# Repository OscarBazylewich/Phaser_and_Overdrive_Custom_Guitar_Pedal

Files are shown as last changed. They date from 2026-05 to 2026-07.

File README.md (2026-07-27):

# Phaser_and_Overdrive_Custom_Guitar_Pedal
This projects attemps to recreate and try to improve upon popular guitar pedals such as the MXR Phase 90 and the BOSS-OD1 by incorporating modern analog circuit design and PCB design. This repository will include an LTSpice schematic as well as 3rd party components utilized in the schematic. The same thing also applies for KiCAD.

Final Project PCB layout:  


How to import 3rd Party Models in LTSpice:
1. Download .sub and .asy files in the LTSpice found in the LTSpice folder.
2. Place the associated files to your local LTSpice directory where the .sub files go into the sub folder and the .asy files fo into the sym folder.

note: 3rd party models might get deleted once ltspice gets updated so its recommended to have a separate folder containing all your 3rd party models then manually copying each file into the directory.

How to import 3rd party symbols, footprints, and models into KiCAD:
1. Place and extract zip files into a directory of your choosing.
2. To import symbols, go into the symbol editor and click on the preferences tab and head onto manage symbol libraries. Then, click the folder icon and look for the directiory where you placed your zip files and import files ending in .kicad_sym.
3. For footprints, go into the footprint editor and click on the preferences tab and head onto manage footprint libraries. Then, click the folder icon and look for the directiory where you placed your zip files and import files ending in .kicad_mod.

Preview of Circuit in LTSpice



Sample Simulations of the circuit





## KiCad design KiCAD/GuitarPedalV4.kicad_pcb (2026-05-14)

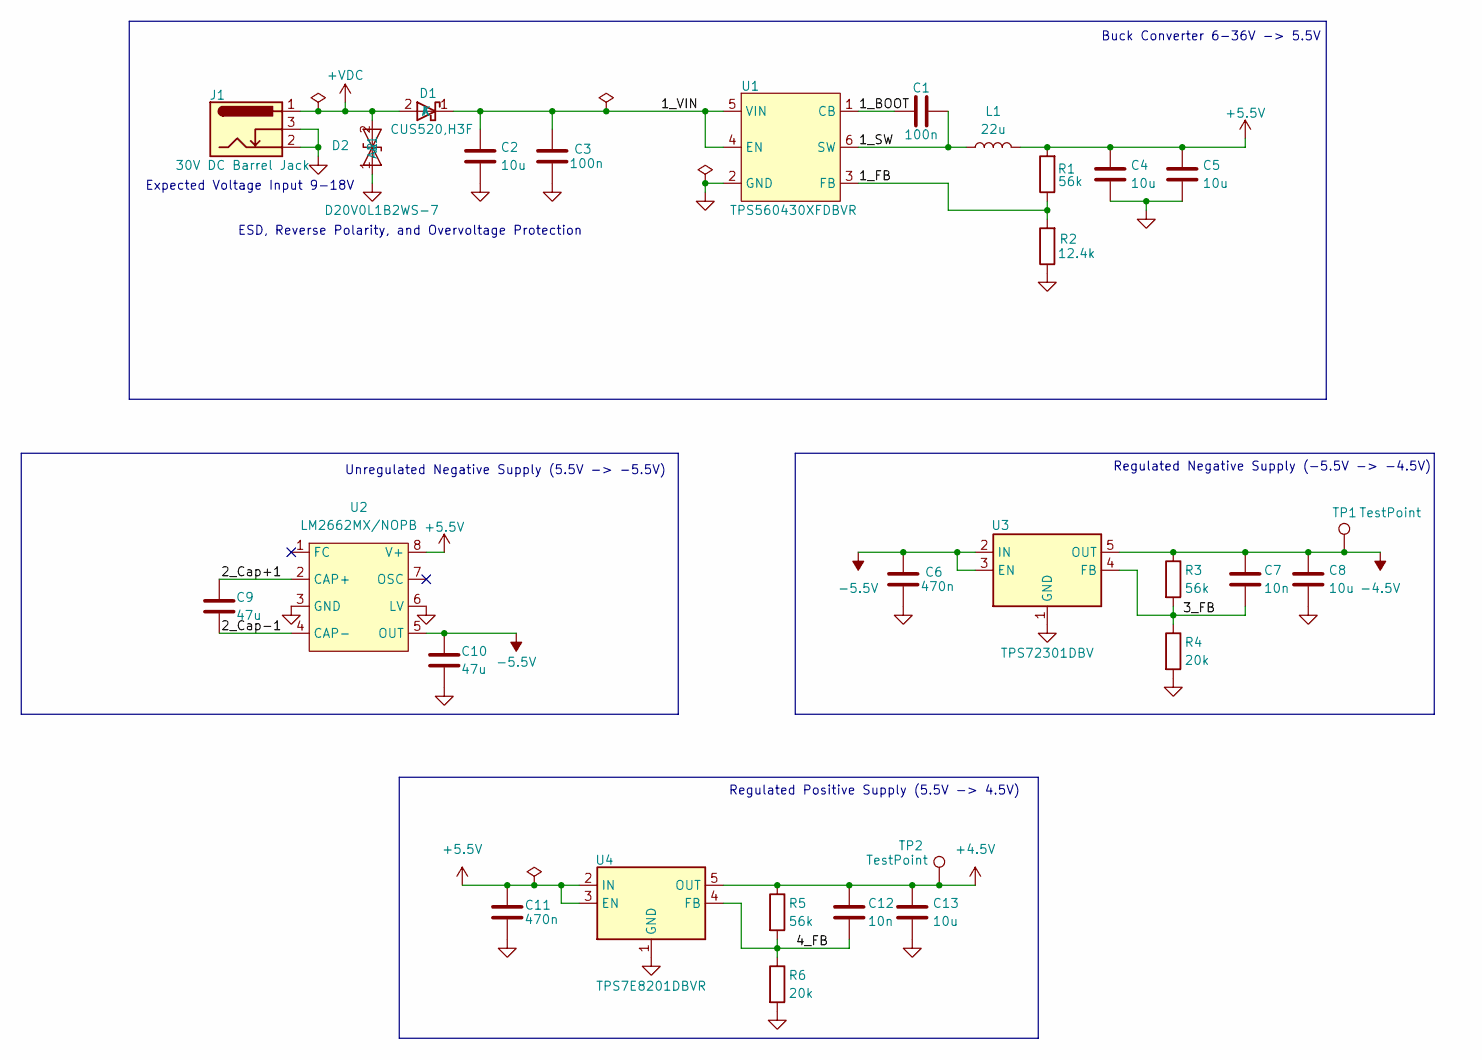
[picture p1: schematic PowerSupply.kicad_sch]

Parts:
C1, C3: 100n; C_0603_1608Metric_Pad1.08x0.95mm_HandSolder; Manufacturer Part Number C1608X5R1H104K080AA
C2, C4, C5, C8, C13: 10u; C_0805_2012Metric_Pad1.18x1.45mm_HandSolder; Manufacturer Part Number C2012X5R1H106K125AC
C6, C11: 470n; C_0603_1608Metric_Pad1.08x0.95mm_HandSolder; Manufacturer Part Number CGA3E1X7R1V474K080AC
C7, C12: 10n; C_0603_1608Metric_Pad1.08x0.95mm_HandSolder; Manufacturer Part Number CGA3E2X7R1H103K080AA
C9, C10: 47u; C_1206_3216Metric_Pad1.33x1.80mm_HandSolder; Manufacturer Part Number C3216X5R1E476M160AC
D1: CUS520,H3F; D_SOD-323_HandSoldering; Manufacturer Part Number CUS520,H3F
D2: D20V0L1B2WS-7; D_SOD-323_HandSoldering; Manufacturer Part Number D20V0L1B2WS-7
J1: 30V DC Barrel Jack; BarrelJack_GCT_DCJ200-10-A_Horizontal; Manufacturer Part Number 694106301002
L1: 22u; L_0805_2012Metric_Pad1.05x1.20mm_HandSolder; Manufacturer Part Number MLZ2012P220WTD25
R1, R3, R5: 56k; R_0603_1608Metric_Pad0.98x0.95mm_HandSolder; Manufacturer Part Number CRCW060356K0FKEA
R2: 12.4k; R_0603_1608Metric_Pad0.98x0.95mm_HandSolder; Manufacturer Part Number CRCW060312K4FKEA
R4, R6: 20k; R_0603_1608Metric_Pad0.98x0.95mm_HandSolder; Manufacturer Part Number CRCW060320K0FKEC
TP1, TP2: TestPoint; TestPoint_Pad_1.0x1.0mm
U1: TPS560430XFDBVR; SOT-23-6; Manufacturer Part Number TPS560430XFDBVR
U2: LM2662MX/NOPB; SOIC-8_3.9x4.9mm_P1.27mm; Manufacturer Part Number LM2662MX/NOPB
U3: TPS72301DBV; SOT-23-5_HandSoldering; Manufacturer Part Number TPS72301DBVRG4
U4: TPS7E8201DBVR; SOT-23-5_HandSoldering; Manufacturer Part Number TPS7E8201DBVR

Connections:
+4.5V: C12.1, C13.1, R5.1, TP2.1 (1_1), U4.5 (OUT); also elsewhere on the board
+5.5V: C4.1, C5.1, C11.2, L1.2, R1.2, U2.8 (V+), U4.2 (IN), U4.3 (EN)
+VDC: D1.2 (A), D2.2 (A2), J1.1
-4.5V: C7.1, C8.1, R3.1, TP1.1 (1_1), U3.5 (OUT); also elsewhere on the board
-5.5V: C6.2, C10.1, U2.5 (OUT), U3.2 (IN), U3.3 (EN)
/Power Supply Section/1_BOOT: C1.2, U1.1 (CB)
/Power Supply Section/1_FB: R1.1, R2.2, U1.3 (FB)
/Power Supply Section/1_SW: C1.1, L1.1, U1.6 (SW)
/Power Supply Section/1_VIN: C2.1, C3.2, D1.1 (K), U1.4 (EN), U1.5 (VIN)
/Power Supply Section/2_Cap+1: C9.1, U2.2 (CAP+)
/Power Supply Section/2_Cap-1: C9.2, U2.4 (CAP-)
/Power Supply Section/3_FB: C7.2, R3.2, R4.1, U3.4 (FB)
/Power Supply Section/4_FB: C12.2, R5.2, R6.1, U4.4 (FB)
GND: C2.2, C3.1, C4.2, C5.2, C6.1, C8.2, C10.2, C11.1, C13.2, D2.1 (A1), J1.2, J1.3, R2.1, R4.2, R6.2, U1.2 (GND), U2.3 (GND), U2.6 (LV), U3.1 (GND), U4.1 (GND); also elsewhere on the board

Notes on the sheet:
Regulated Negative Supply (-5.5V -> -4.5V)
ESD, Reverse Polarity, and Overvoltage Protection
Regulated Positive Supply (5.5V -> 4.5V)
Unregulated Negative Supply (5.5V -> -5.5V)
Expected Voltage Input 9-18V
Buck Converter 6-36V -> 5.5V

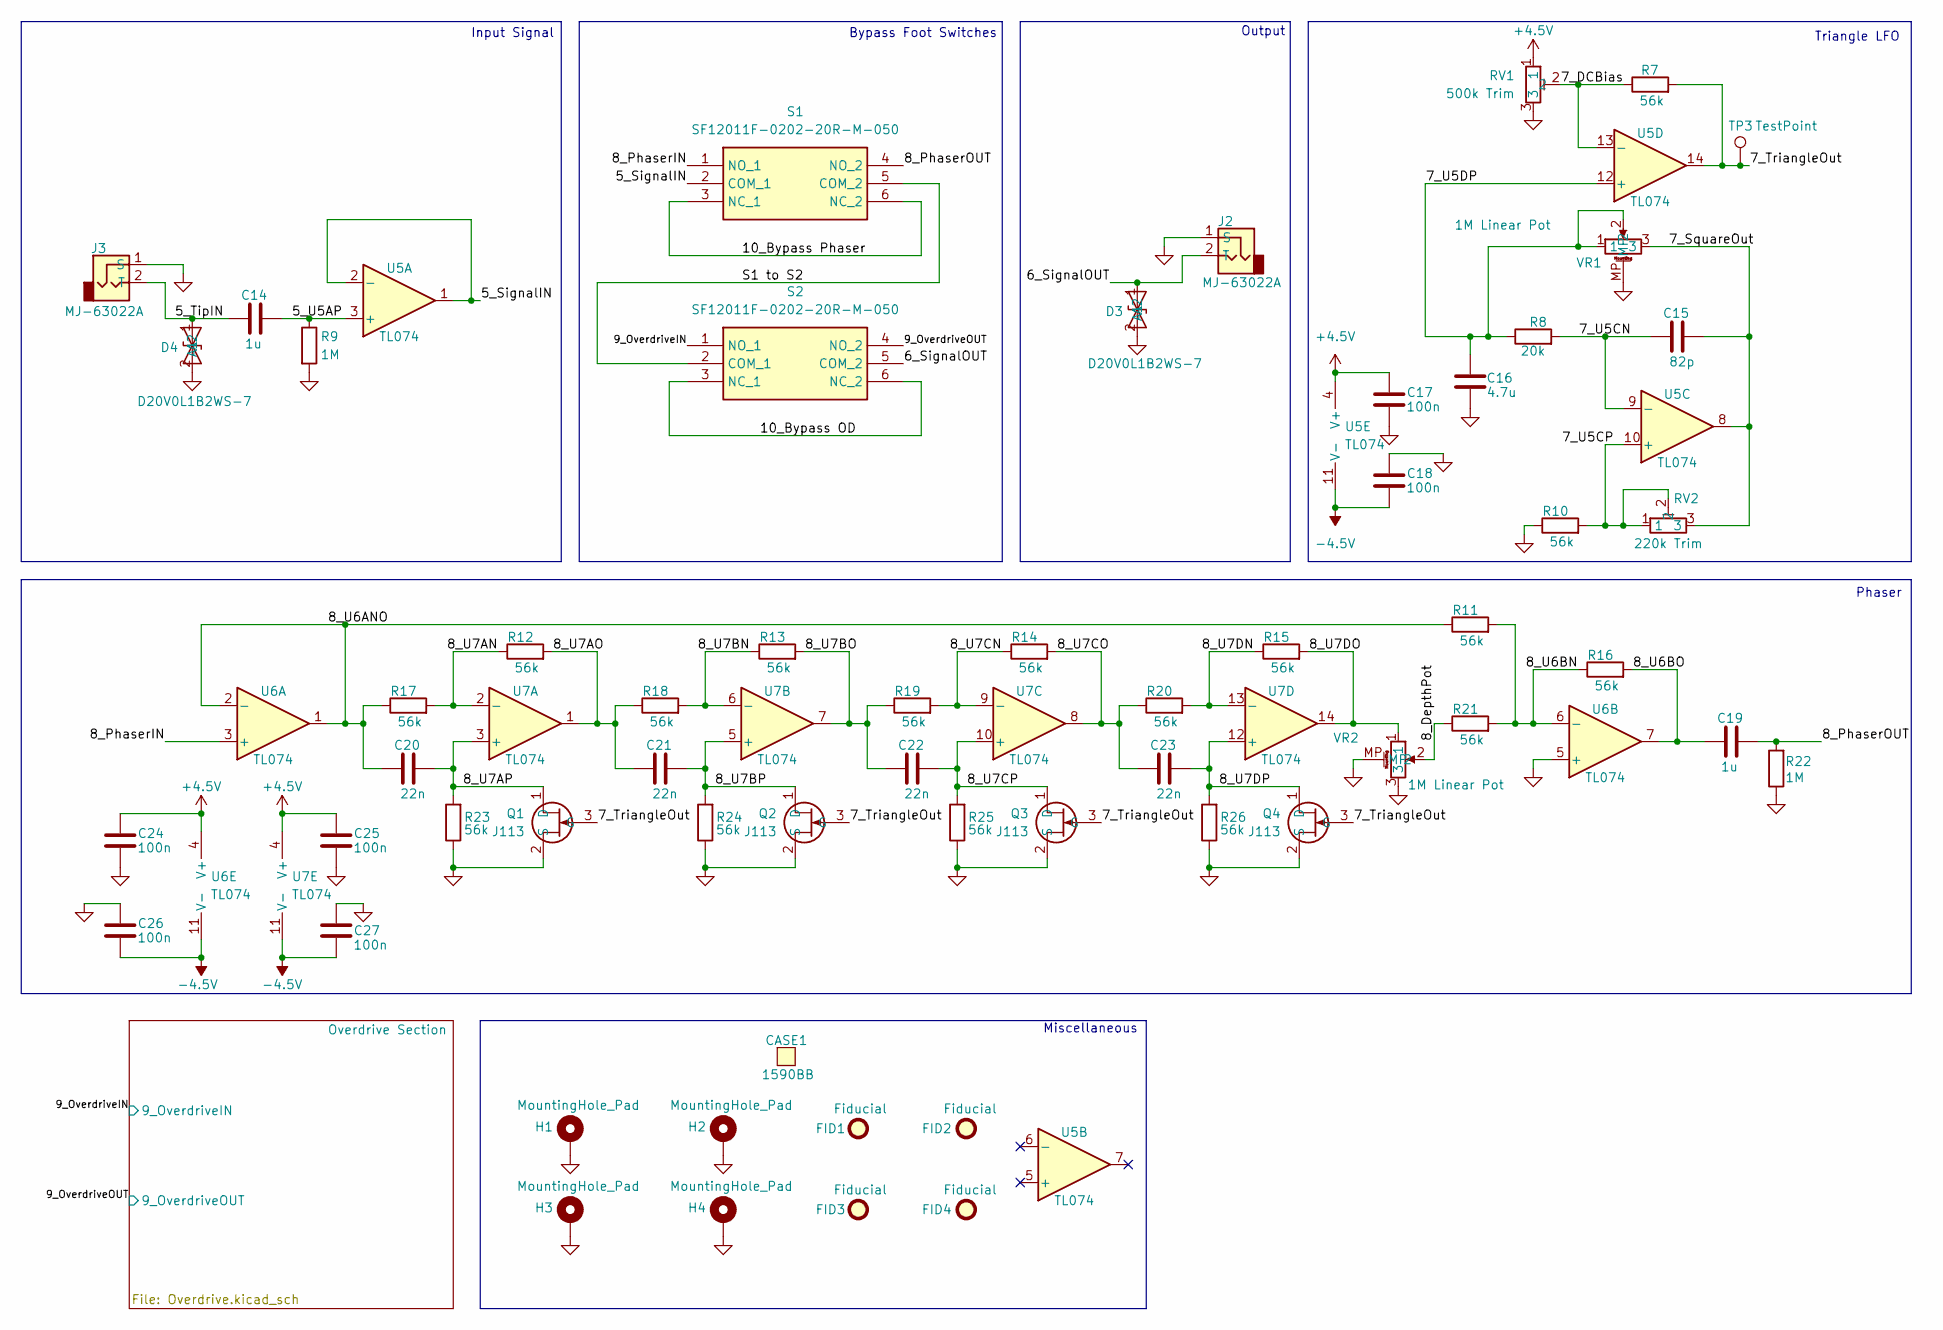
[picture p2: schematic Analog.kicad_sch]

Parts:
C14, C19: 1u; C_Rect_L7.2mm_W4.5mm_P5.00mm_FKS2_FKP2_MKS2_MKP2; Manufacturer Part Number B32529C0105J189
C15: 82p; C_Disc_D3.8mm_W2.6mm_P2.50mm; Manufacturer Part Number K820J15C0GF5TL2
C16: 4.7u; C_Rect_L18.0mm_W7.0mm_P15.00mm_FKS3_FKP3; Manufacturer Part Number B32522C0475J000
C17, C18, C24, C25, C26, C27: 100n; C_0603_1608Metric_Pad1.08x0.95mm_HandSolder; Manufacturer Part Number C1608X5R1H104K080AA
C20, C21, C22, C23: 22n; C_Rect_L7.2mm_W2.5mm_P5.00mm_FKS2_FKP2_MKS2_MKP2; Manufacturer Part Number B32529C1223J289
CASE1: 1590BB; Manufacturer Part Number 1590BB
D3, D4: D20V0L1B2WS-7; D_SOD-323_HandSoldering; Manufacturer Part Number D20V0L1B2WS-7
FID1, FID2, FID3, FID4: Fiducial
H1, H2, H3, H4: MountingHole_Pad; MountingHole_3.2mm_M3_Pad
J2, J3: MJ-63022A; MJ63022A; Manufacturer Part Number MJ-63022A
Q1, Q2, Q3, Q4: J113; 2N3904BU; Manufacturer Part Number J113
R7, R10, R11, R12, R13, R14, R15, R16, R17, R18, R19, R20, R21, R23, R24, R25, R26: 56k; R_0603_1608Metric_Pad0.98x0.95mm_HandSolder; Manufacturer Part Number CRCW060356K0FKEA
R8: 20k; R_0603_1608Metric_Pad0.98x0.95mm_HandSolder; Manufacturer Part Number CRCW060320K0FKEC
R9, R22: 1M; R_0603_1608Metric_Pad0.98x0.95mm_HandSolder; Manufacturer Part Number CRCW06031M00FKEA
RV1: 500k Trim; 3386P1504LF; Manufacturer Part Number 3386P-1-504LF
RV2: 220k Trim; 3386P1504LF; Manufacturer Part Number 3386P-1-224LF
S1, S2: SF12011F-0202-20R-M-050; SF12011F020220RM050; Manufacturer Part Number SF12011F-0202-20R-M-050
TP3: TestPoint; TestPoint_Pad_1.0x1.0mm
U5, U6, U7: TL074; SOIC-14_3.9x8.7mm_P1.27mm; Manufacturer Part Number TL074HIDR
VR1, VR2: 1M Linear Pot; PTV09A4025FA105; Manufacturer Part Number PTV09A-4020F-B105

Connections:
+4.5V: C17.2, C24.2, C25.2, RV1.1, U5.4 (V+), U6.4 (V+), U7.4 (V+); also elsewhere on the board
-4.5V: C18.1, C26.1, C27.1, U5.11 (V-), U6.11 (V-), U7.11 (V-); also elsewhere on the board
/Analog Section/5_SignalIN: S1.2 (COM_1), U5.1, U5.2 (-)
/Analog Section/5_TipIN: C14.1, D4.1 (A1), J3.2 (T)
/Analog Section/5_U5AP: C14.2, R9.1, U5.3 (+)
/Analog Section/6_SignalOUT: D3.1 (A1), J2.2 (T), S2.5 (COM_2)
/Analog Section/7_DCBias: R7.1, RV1.2, U5.13 (-)
/Analog Section/7_SquareOut: C15.2, RV2.3, U5.8, VR1.3
/Analog Section/7_TriangleOut: Q1.3 (G), Q2.3 (G), Q3.3 (G), Q4.3 (G), R7.2, TP3.1 (1_1), U5.14
/Analog Section/7_U5CN: C15.1, R8.2, U5.9 (-)
/Analog Section/7_U5CP: R10.2, RV2.1, RV2.2, U5.10 (+)
/Analog Section/7_U5DP: C16.2, R8.1, U5.12 (+), VR1.1, VR1.2
/Analog Section/8_DepthPot: R21.1, VR2.2
/Analog Section/8_PhaserIN: S1.1 (NO_1), U6.3 (+)
/Analog Section/8_PhaserOUT: C19.2, R22.2, S1.4 (NO_2)
/Analog Section/8_U6ANO: C20.1, R11.1, R17.1, U6.1, U6.2 (-)
/Analog Section/8_U6BN: R11.2, R16.1, R21.2, U6.6 (-)
/Analog Section/8_U6BO: C19.1, R16.2, U6.7
/Analog Section/8_U7AN: R12.1, R17.2, U7.2 (-)
/Analog Section/8_U7AO: C21.1, R12.2, R18.1, U7.1
/Analog Section/8_U7AP: C20.2, Q1.1 (D), R23.2, U7.3 (+)
/Analog Section/8_U7BN: R13.1, R18.2, U7.6 (-)
/Analog Section/8_U7BO: C22.1, R13.2, R19.1, U7.7
/Analog Section/8_U7BP: C21.2, Q2.1 (D), R24.2, U7.5 (+)
/Analog Section/8_U7CN: R14.1, R19.2, U7.9 (-)
/Analog Section/8_U7CO: C23.1, R14.2, R20.1, U7.8
/Analog Section/8_U7CP: C22.2, Q3.1 (D), R25.2, U7.10 (+)
/Analog Section/8_U7DN: R15.1, R20.2, U7.13 (-)
/Analog Section/8_U7DO: R15.2, U7.14, VR2.1
/Analog Section/8_U7DP: C23.2, Q4.1 (D), R26.2, U7.12 (+)
/Analog Section/9_OverdriveIN: S2.1 (NO_1); also elsewhere on the board
/Analog Section/9_OverdriveOUT: S2.4 (NO_2); also elsewhere on the board
/Analog Section/10_Bypass OD: S2.3 (NC_1), S2.6 (NC_2)
/Analog Section/10_Bypass Phaser: S1.3 (NC_1), S1.6 (NC_2)
/Analog Section/S1 to S2: S1.5 (COM_2), S2.2 (COM_1)
GND: C16.1, C17.1, C18.2, C24.1, C25.1, C26.2, C27.2, D3.2 (A2), D4.2 (A2), H1.1 (1_1), H2.1 (1_1), H3.1 (1_1), H4.1 (1_1), J2.1 (S), J3.1 (S), Q1.2 (S), Q2.2 (S), Q3.2 (S), Q4.2 (S), R9.2, R10.1, R22.1, R23.1, R24.1, R25.1, R26.1, RV1.3, U6.5 (+), VR1.MP, VR2.3, VR2.MP; also elsewhere on the board

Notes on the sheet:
Phaser
Miscellaneous
Output
Bypass Foot Switches
Input Signal
Triangle LFO

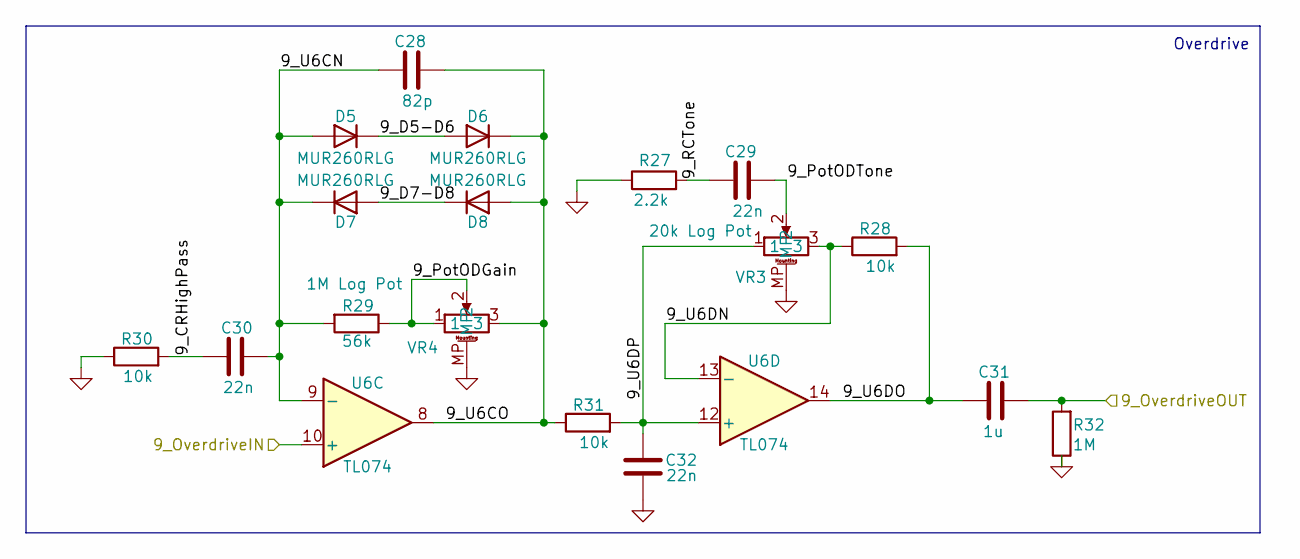
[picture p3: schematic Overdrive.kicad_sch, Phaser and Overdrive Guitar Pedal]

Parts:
C28: 82p; C_Disc_D3.8mm_W2.6mm_P2.50mm; Manufacturer Part Number K820J15C0GF5TL2
C29, C30, C32: 22n; C_Rect_L7.2mm_W2.5mm_P5.00mm_FKS2_FKP2_MKS2_MKP2; Manufacturer Part Number B32529C1223J289
C31: 1u; C_Rect_L7.2mm_W4.5mm_P5.00mm_FKS2_FKP2_MKS2_MKP2; Manufacturer Part Number B32529C0105J189
D5, D6, D7, D8: MUR260RLG; D_DO-35_SOD27_P7.62mm_Horizontal; Manufacturer Part Number MUR260RLG
R27: 2.2k; R_0603_1608Metric_Pad0.98x0.95mm_HandSolder; Manufacturer Part Number CRCW06032K20FKEA
R28, R30, R31: 10k; R_0603_1608Metric_Pad0.98x0.95mm_HandSolder; Manufacturer Part Number CRCW060310K0FKEA
R29: 56k; R_0603_1608Metric_Pad0.98x0.95mm_HandSolder; Manufacturer Part Number CRCW060356K0FKEA
R32: 1M; R_0603_1608Metric_Pad0.98x0.95mm_HandSolder; Manufacturer Part Number CRCW06031M00FKEA
U6: TL074; SOIC-14_3.9x8.7mm_P1.27mm; Manufacturer Part Number TL074HIDR
VR3: 20k Log Pot; PTV09A4025FA105; Manufacturer Part Number PTV09A-4025F-A203
VR4: 1M Log Pot; PTV09A4025FA105; Manufacturer Part Number PTV09A-4025F-A105

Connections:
/Analog Section/9_OverdriveIN: U6.10 (+); also elsewhere on the board
/Analog Section/9_OverdriveOUT: C31.2, R32.2; also elsewhere on the board
/Analog Section/Overdrive Section/9_CRHighPass: C30.2, R30.2
/Analog Section/Overdrive Section/9_D5-D6: D5.1 (K), D6.2 (A)
/Analog Section/Overdrive Section/9_D7-D8: D7.2 (A), D8.1 (K)
/Analog Section/Overdrive Section/9_PotODGain: R29.1, VR4.1, VR4.2
/Analog Section/Overdrive Section/9_PotODTone: C29.2, VR3.2
/Analog Section/Overdrive Section/9_RCTone: C29.1, R27.2
/Analog Section/Overdrive Section/9_U6CN: C28.1, C30.1, D5.2 (A), D7.1 (K), R29.2, U6.9 (-)
/Analog Section/Overdrive Section/9_U6CO: C28.2, D6.1 (K), D8.2 (A), R31.1, U6.8, VR4.3
/Analog Section/Overdrive Section/9_U6DN: R28.1, U6.13 (-), VR3.3
/Analog Section/Overdrive Section/9_U6DO: C31.1, R28.2, U6.14
/Analog Section/Overdrive Section/9_U6DP: C32.2, R31.2, U6.12 (+), VR3.1
GND: C32.1, R27.1, R30.1, R32.1, VR3.MP, VR4.MP; also elsewhere on the board

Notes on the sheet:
Overdrive

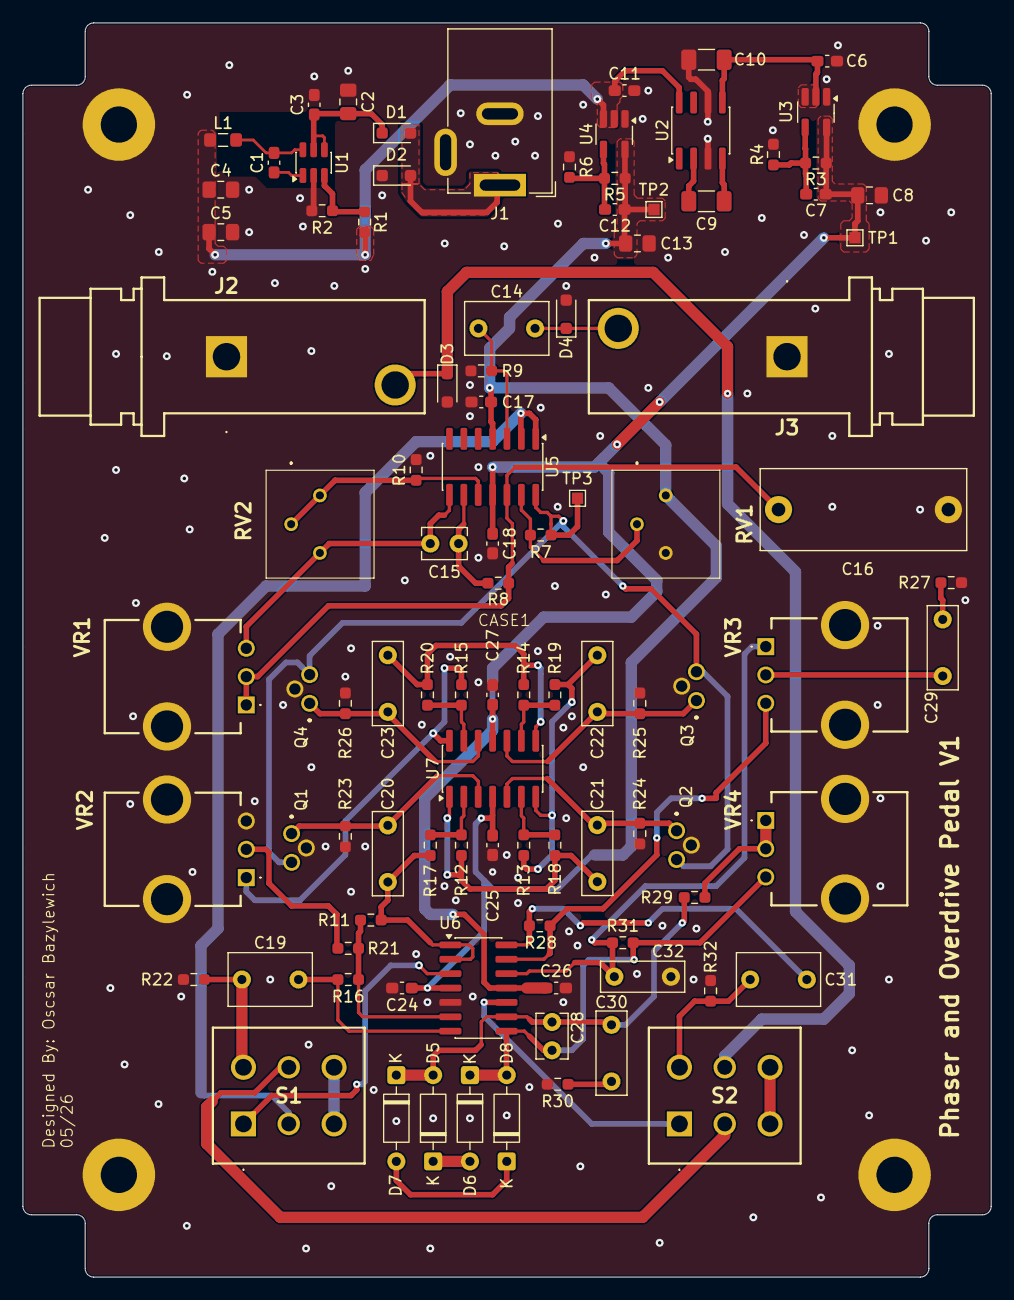
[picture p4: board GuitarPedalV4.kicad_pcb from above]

Board: 4 copper layers, 85.5 x 110.8 mm, 103 parts (0 on the bottom side), 58 nets.

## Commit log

2026-11-03 Rewrite README and tidy the KiCad folder
    Document the signal flow, parts, controls, switch wiring, PCB stack-up
    and each circuit stage, with LTspice and KiCad setup steps and fixed
    library instructions. Move the symbol/footprint library zips into
    KiCAD/Libraries/, delete the empty KiCAD/a placeholder, and add
    .gitattributes so GitHub counts KiCad files in language stats.
2026-11-03 Shorten README and match my writing style
    Cut the README to about half its length, reuse my original wording
    where it is still accurate, and keep the verified facts and images.
2026-11-09 Changes the TPS7E8201 symbol pins and the PCB tracks
    The TPS7E82 symbol had the IN pin and the GND pin in the incorrect positions. This version has the correct symbol, U4 pads and PCB tracks.
    The KiCad files also have two part changes. The clipping diodes D5 to D8 change to 1N4148. The footswitches S1 and S2 change to the latching type.
    The DIY library ZIP file has the correct symbol. The README shows the new diode part number.
